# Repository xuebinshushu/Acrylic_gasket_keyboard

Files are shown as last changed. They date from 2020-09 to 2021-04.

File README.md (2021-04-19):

# Acrylic_gasket_keyboard

Stacked acrylic sheets to make a keyboard shell with a gasket structure including positioning plates.

本项目基于blacase 315 绘制，并使用MIT开源许可。

20210419 修改：

- 收紧边框尺寸

20210411 修改（图片来自群友）：

- 建议使用poron垫片作为定位板的承载条，去掉了亚克力的教条开槽。

- 对脚撑进行修改，改为纵向脚撑，更加美观。

- 将更改后的螺丝规格放在了图纸里。

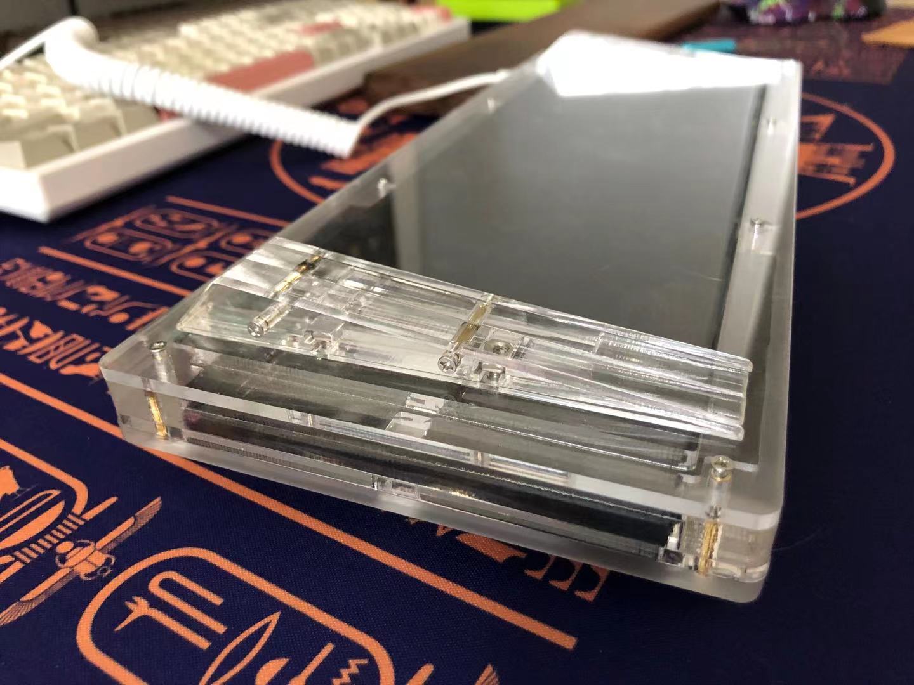
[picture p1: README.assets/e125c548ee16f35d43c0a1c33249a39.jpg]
e125c548ee16f35d43c0a1c33249a39


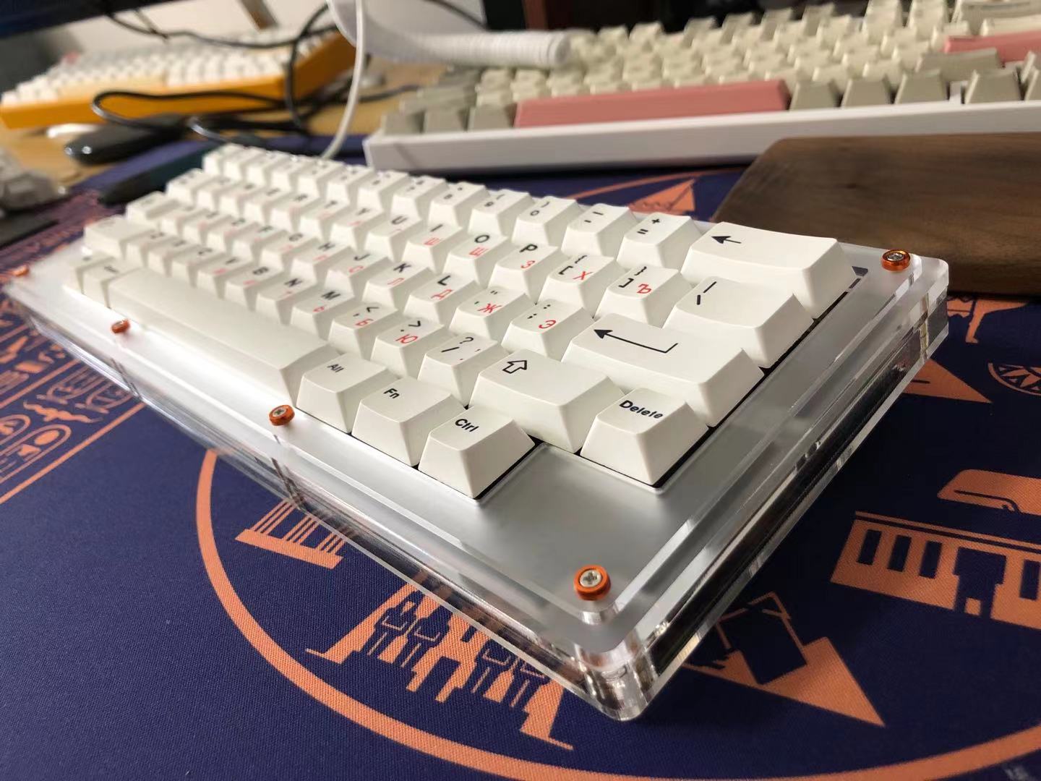
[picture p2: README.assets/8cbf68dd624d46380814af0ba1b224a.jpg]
8cbf68dd624d46380814af0ba1b224a


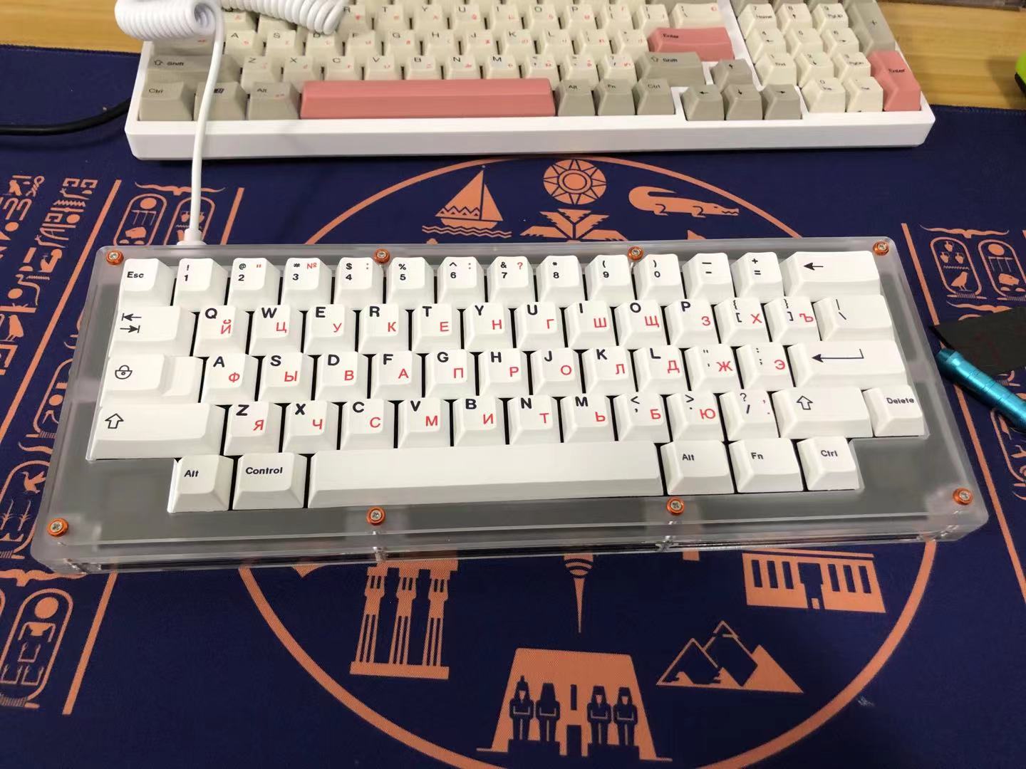
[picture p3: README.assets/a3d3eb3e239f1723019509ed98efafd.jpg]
a3d3eb3e239f1723019509ed98efafd


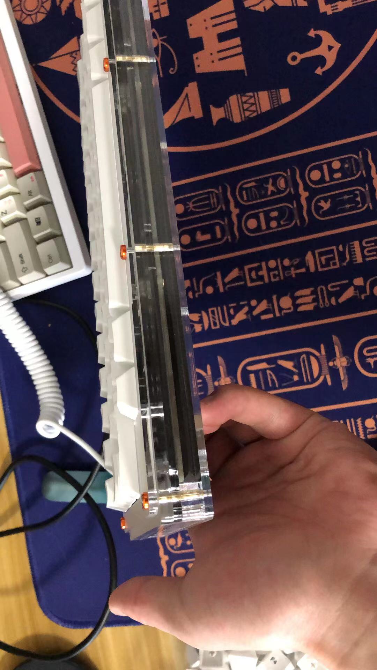
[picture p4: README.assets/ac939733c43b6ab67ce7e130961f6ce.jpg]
ac939733c43b6ab67ce7e130961f6ce


本项目特色：

- 将原三明治结构改成gakset结构
- 一层阶梯层，其余层完全相同尺寸，除第一层外无阶梯。本人喜欢这样的设计，去掉了其他层的阶梯，见仁见智。
- 层加定位板外圈亚克力，来承受螺丝向心力。
- 定位板与外圈有1mm的旷量，装配时适当调整可以避免定位板与壳子之间硬接触，达到真正的gasket目的。
- 定位板推荐做1.5mm铝定位。配合gmk原厂键帽声音好听直接能出雨滴音。
- 增加了大门牙上盖。
- 兼容GH60尺寸的60配列PCB。只做了非左移大兼容定位板，如果需要，请自己根据定位板外框尺寸进行更改。
- 淘宝购买4mm泡发胶条，别买错了，我第一次就买成了左边这种，比较硬，大家自行购买右边的这种白色软的泡发硅胶条。店铺不贴了，只告诉大家别花冤枉钱，这个东西不贵。

20200916 补充

- 调整胶条开槽位置 

- 接受大家建议，修改螺丝孔为3.2，放弃使用3.5mm螺丝柱，相对普遍一些，下面有附上螺丝柱尺寸

    | 常规       | 尺寸                        | 数量 |
    | ---------- | --------------------------- | ---- |
    |            | m2*15 螺丝柱（外径3.2）     | 6    |
    |            | m2*25 螺丝柱（外径3.2）     | 2    |
    |            | m2*8 沉头螺丝               | 10   |
    |            | m2*6 半圆头螺丝（可选沉头） | 6    |
    |            | m2 沉头垫片（选装）         | 10   |
    | **电池仓** |                             |      |
    |            | m2*8 螺丝柱（外径3.2）      | 4    |
    |            | m2*4 螺丝                   | 8    |
    |            | m2 垫片（选装）             | 4    |

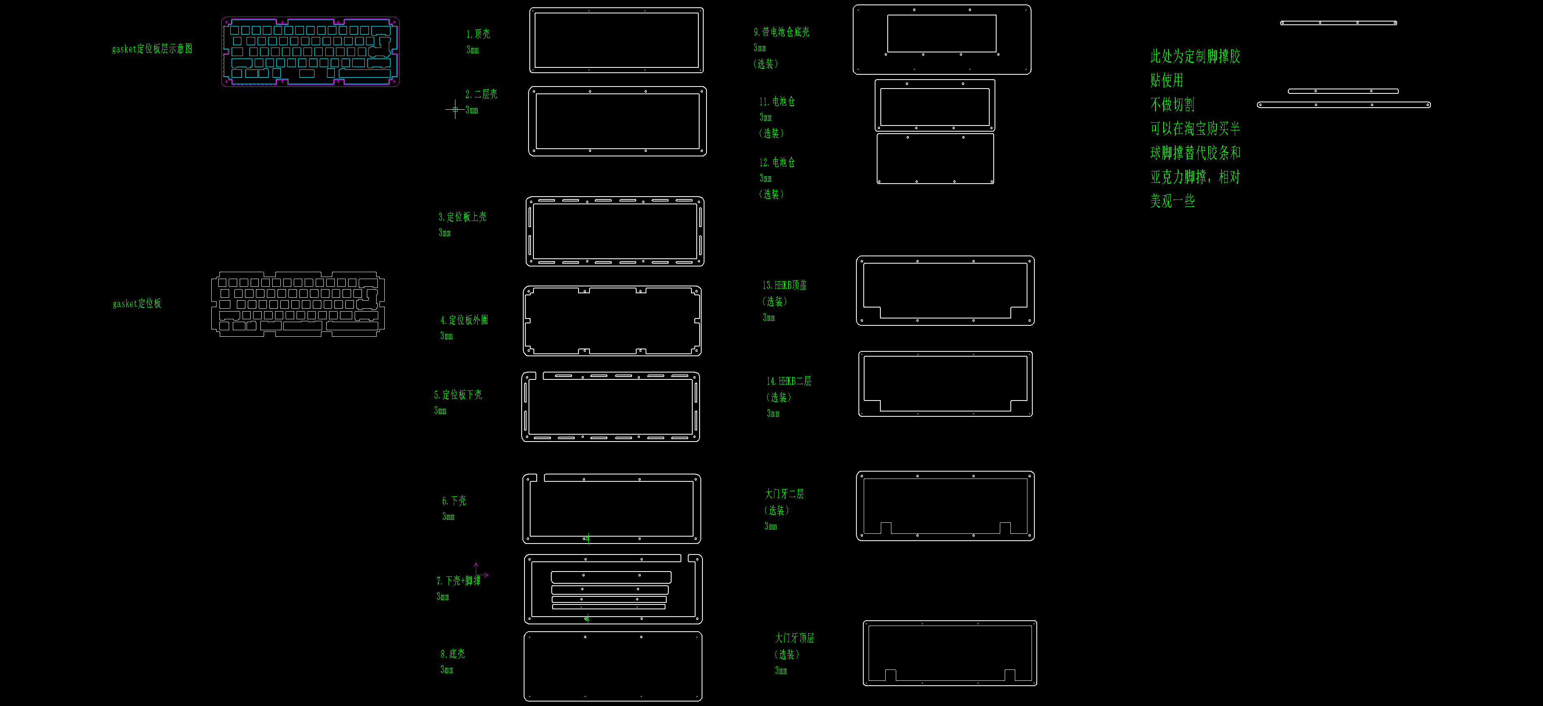
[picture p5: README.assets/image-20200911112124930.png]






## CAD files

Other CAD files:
Acrylic_gasket_keyboard.dwg
Plate.dwg

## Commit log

2020-09-11 Acrylic_gasket_case & plate
    [Acrylic_gasket_keyboard.dwg]
2020-09-11 add alone plate file
    [Plate.dwg]
2020-09-14 add gasket
    [Acrylic_gasket_keyboard.dwg]
2020-12-16 修改螺丝孔3.2mm
    [Acrylic_gasket_keyboard.dwg]
2021-04-10 改变脚撑&使用垫片
    [Acrylic_gasket_keyboard.dwg]
2021-04-10 修改说明
2021-04-11 添加螺母图例
    [Acrylic_gasket_keyboard.dwg]
2021-04-19 收紧边框尺寸
    [Acrylic_gasket_keyboard.dwg]
